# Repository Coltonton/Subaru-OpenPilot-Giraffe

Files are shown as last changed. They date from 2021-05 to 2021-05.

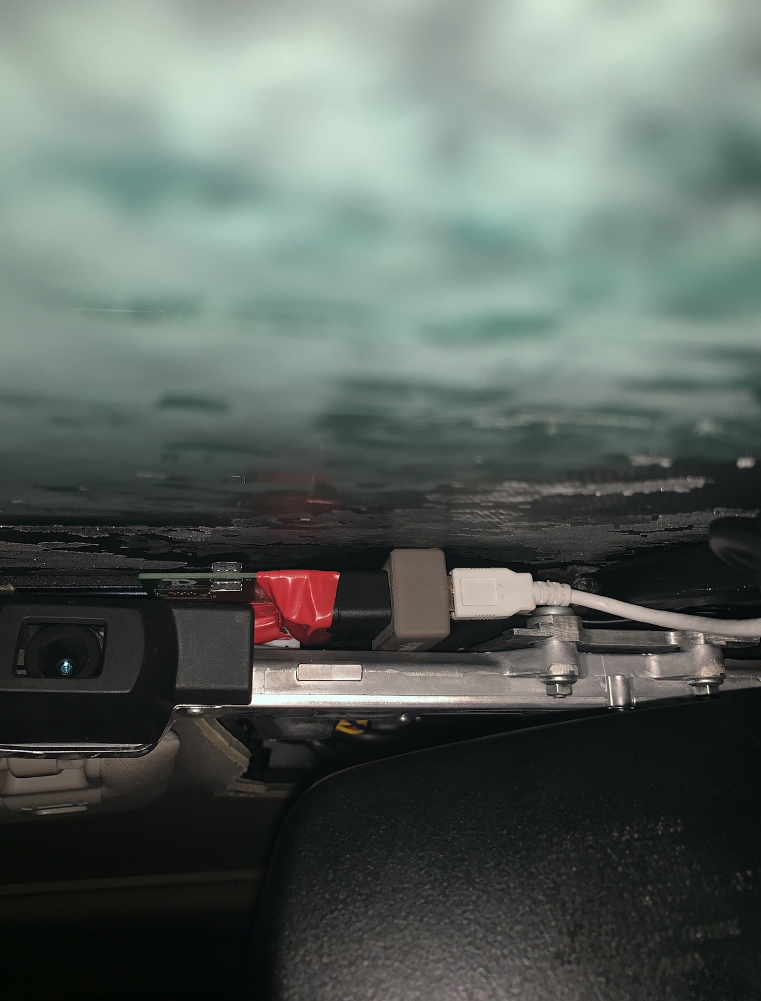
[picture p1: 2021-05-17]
Pictures/V3/Installation Example.jpg

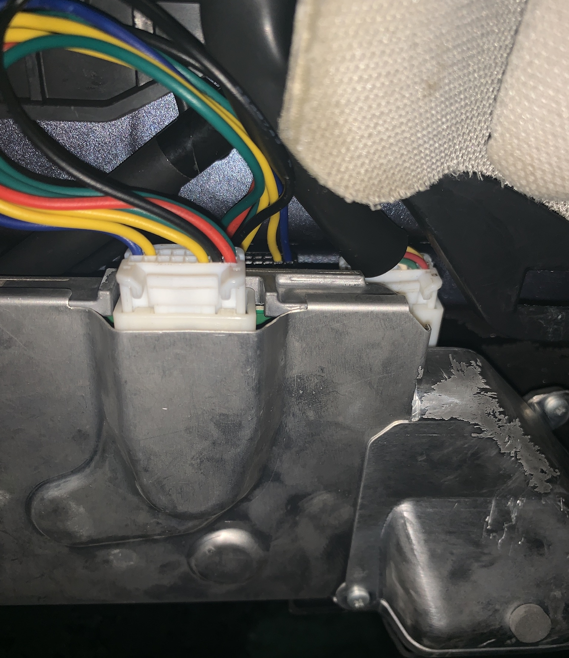
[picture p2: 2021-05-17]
Pictures/V3/3.0-3.6 Installation Example.jpg

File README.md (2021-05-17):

 
# Subaru-OpenPilot-Giraffe(s) 

Here lies the olden and golden days of OpenPilot with Giraffes! You can use this product to interface with the CAN bus on your Subaru vehicle at EyeSight, giving the bonus ability to isolate the EyeSight module on its own separate CAN network for vehicle research, and hacking. 

Some of the Giraffes have mistakes, everything in the `/Legacy Archival Giraffes` folder is just that, a digital archive of most of my work. Most of the "development" Giraffes are lost to time and poor archival management, but live in the release of that version. DO NOT use these files as reference to build your own. ONLY use Austin, Cynthia, or Linda. 

- Intended to be used with a [Comma.ai White or Grey Panda](https://comma.ai/shop/products/panda) 

# Versions  
## -V3- 
 

3.0 Was the real move and evolution, finally fitting it in the cover (Also what the **Smol Bugsy Giraffe** tried to accomplish but in a different way.) I decided to stick on this path for a variety of reasons! I figured out there was no room under the cover... HOWEVER there was tons of room between the top of the EyeSight unit and the roof of the car. I already basically figured it out tho with [V1.1](#). Sometimes you have to look to the past to answer questions today! Again I was over-Zellous with V1.1; but with sure luck, the space allotted to me by the Subaru engineers was a near perfect fit for Panda... Not even a MM of clearance at the smallest point. Working even more perfectly. So is born V3! Only taking to V3 Rev 4 (NIKI) to come up with the perfect and final layout; even solving my switch problem by making the board big enough to where the switches would just be at the gap between the windshield and trim piece. giving a still invisible appearance, but not to difficult to actuate! Progress was made here!  

The V3 also brought reverse compatibility with already dead hardware (The Comma NEO) And was designed to have the factory connector pass above the EyeSight camera unit, plug into giraffe, then having a jumper connector to EyeSight. This ended up only being a possibility for the Legacy/Outback models. All other Subarus did not have the room for the chonky stock connector. Sparking V3.7+ with its Y connector to pass above the camera unit. (I still prefer the Linda design, was nicer and ALOT easier to produce....) 

### -V3.8.3 Austin- 
 

This is a very special edition of the Subaru Giraffe, not only is it the last version to be released; but it was sold as special edition Giraffe. Released in a special blue PCB and dedicated to the memory of my friend and classmate from grade school, Austin, who was tragically taken from us March 20th, 2019; at the too young age of 19. Until we meet again... 

This revision is still very near and dear to my heart and it pained me to no longer use it in my vehicle daily being forced to upgrade to a Black Panda, it's now on my desk where I get to see it daily. But enough with the wishy-washy crap and onto the info! As you can prolly tell by the x.x.3 i screwed this revision up.... a-couple times.... 

- The DeFacto Standard, this is what you should use! 

- Is the "gloabal platform" release Giraffe for use in all Subarus, whereas all previous V3 Giraffes were designed around a 2015 Legacy (and has a lot more room to play) 

- Replaced the 3.7 Cynthia as this version was a 3.7 special edition! But its the same thing 

### -V3.7 Cynthia- 

 
- First iteration of the Subaru global support 

- See [Austin](#V3.8.3-Austin) for details, they are the same, [Austin](#V3.8.3-Austin) is just a special edition of Cynthia with more beautiful routing! 

### -V3.6 Linda- 
 

- 2015-2019 Legacy/Outback Only 
- Added Subaru RAB Support 
- Added New Comma (Camera on CAN 3 instead of 2) Support 

### -V3.4 Niki- 
 

- 2015-2019 Legacy/Outback Only 
- Non RAB (Reverse Automatic Braking) Subarus ONLY 

### -V3.2 & V3.3 Gem- 
 

- 2015-2019 Legacy/Outback Only 
- Non RAB (Reverse Automatic Braking) Subarus ONLY 

### -V3.1 VIKI- 
 

- What Autum was supposed to be 

### -V3.0 Autumn- 
Dedicated to the memory of a co-worker who died unexpectedly, Autumn, to launch the 3rd generation of Subaru Giraffes (Non Working) 

## -V2- 
 

2.0 is a perfect example of my mind thinking more complex at first then working to simplicity. The idea with this weird Giraffe was to be like all the other Giraffes at the time where the board plugs directly into the cameras and the factory harness plugs into the board. This was a stupid idea as it would require cutting the EyeSight cover (or having it off) Witch we already had agreed was not going to happen... Too ugly, and expensive. It made a great development board as we were still trying to get the Subaru port "functional" It even uses the exact dip switches as the others. But with a twist... My overengineering mind went crazy with ideas as I knew the Giraffe would end up getting hidden up in the cover; I still wanted an easy way to have the traditional "switches" to be able to toggle Stock/Openpilot. What did I do? the only logical thing of course relays that could be hooked up to a switch and ran! It was a development platform so the *idea* was to be able to choose between dip switches or relay. I'm pretty sure they wouldn't work anyway as they are Solid state relays... idk... never tried them... 

It's funny because a year later Comma.ai made the **Subaru Access Point** with... a relay..... to control switching.... Eventually becoming the [Comma Harnes](https://comma.ai/shop/products/comma-car-harness)....  Admittedly they did do it better.... Except for using the USB Type-C Connectors...... It would of been the eventual evolution of my product to go back to relay control anyway! I take one big leap, have to crawl backwards crying and work my way back.....   

## -V1- 
 

Mr Overthinkers, first Giraffe overthink, before I found out Panda did fit somewhere in the EyeSight cover I had the brilliant idea to tear apart the Comma Panda and just put it on the Giraffe 

Rip White Panda - unknown year 

Features Eletronic relays that could be used to solve our switch situation (im writing this in reverse order so see V2 for info on that....) 

## -V0.1- 
 

**My First PCB** features include: 
- 90deg track corners 
- Weird angle lines (non 45deg multiple) 
- OBD socket doesn't even fit 
- Eyesight connectors don't even fit 
- No idea what I was doing (clearly) 
- Absolute trash 
- Prolly will blow up your car

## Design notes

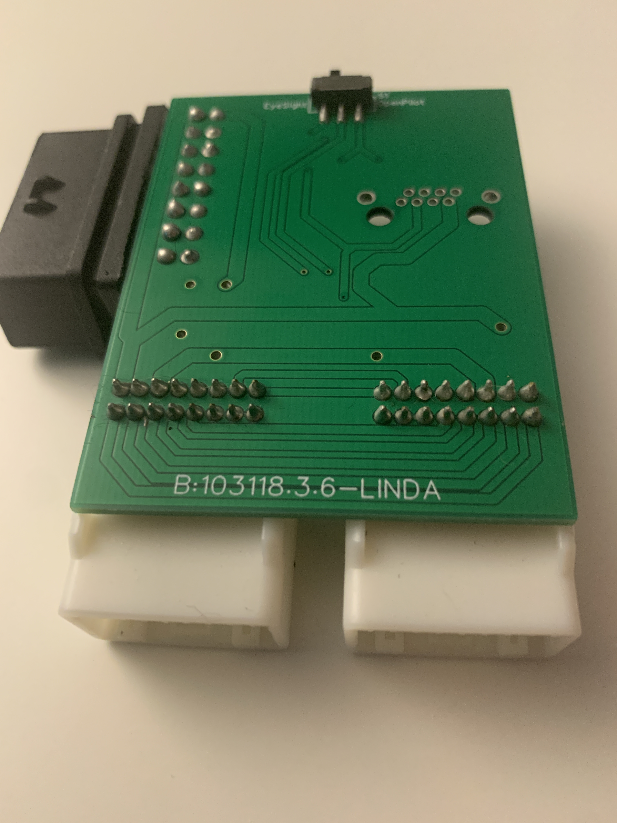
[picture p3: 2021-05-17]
Pictures/V3/3.6-Linda(1).JPG

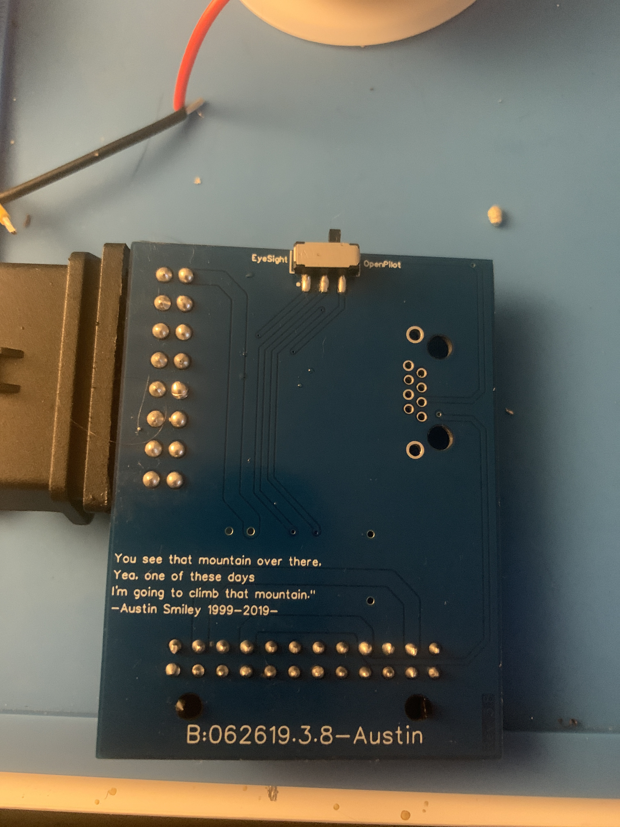
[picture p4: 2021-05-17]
Pictures/V3/3.8-Austin(1).JPG

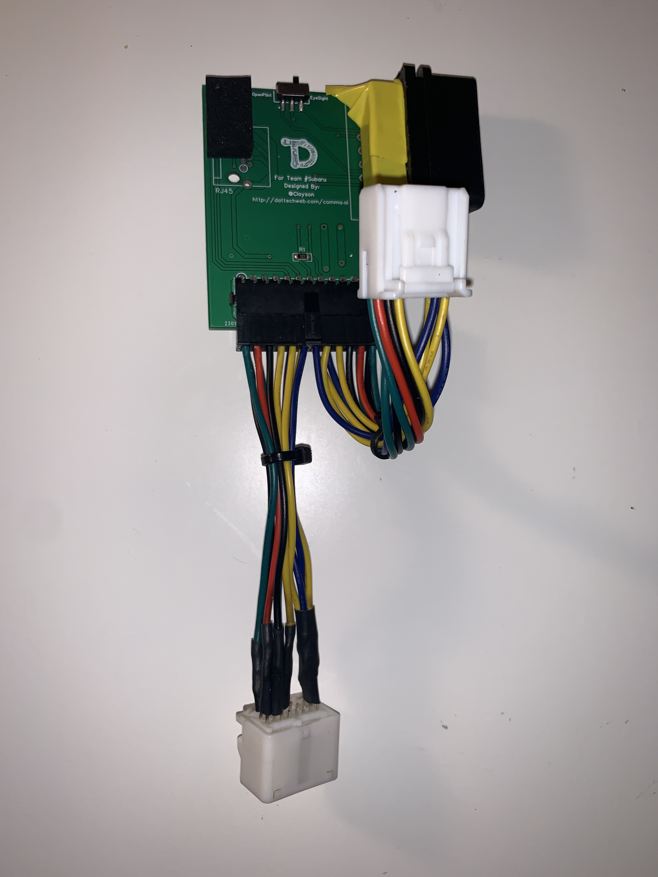
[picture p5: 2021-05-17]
Pictures/V3/3.7-Cynthia(5).JPG

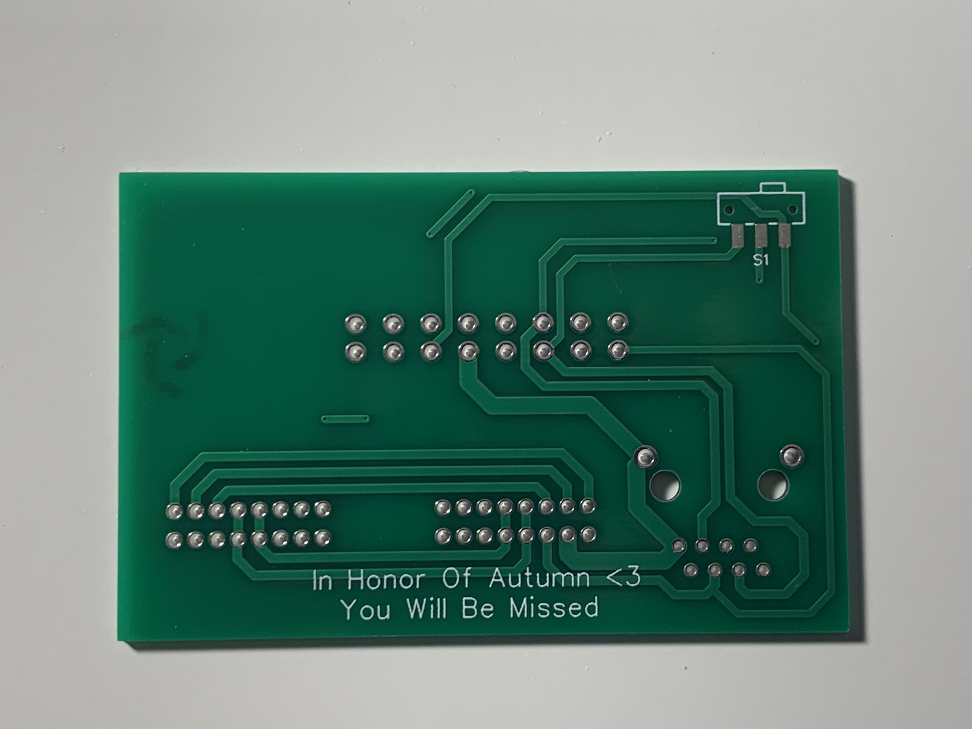
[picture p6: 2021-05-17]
Pictures/V3/3.0-Autumn.JPG

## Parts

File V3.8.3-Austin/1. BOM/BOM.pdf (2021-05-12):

Manufacturer Part Number | Manufacturer | Digi-Key Part Number | Customer Reference | Reference Designator Quantity
2-794617-4 | TE Connectivity AMP Connectors | A30304-ND | | Y3 | 1
5-794618-4 | TE Connectivity AMP Connectors | A33262-ND | | CON HEADER F | 1
794610-1 | TE Connectivity AMP Connectors | A30305-ND | | | 24
KTR18EZPJ121 | Rohm Semiconductor | RHM120PCT-ND | | R1 | 1
JS102011SAQN | C&K | 401-1999-1-ND | | CANH & CANL | 2
1318382-2 | TE Connectivity AMP Connectors | A126093-ND | EyeSight Input | Y1 | 1
1318386-1 | TE Connectivity AMP Connectors | A106550-ND | To EyeSight | Y2 | 1
1123343-1 | TE Connectivity AMP Connectors | A107011CT-ND | | | 12
OBDII 16 Pin J1962 F 90deg | Alibaba (Or Me, I Have some) | | | panda | 1
https://www.alibaba.com/product-detail/OBD2-OBDII-16-Pin-J1962-Female_60735154017.html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

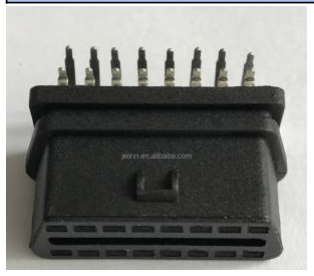
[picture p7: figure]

I Extras of this OBDII Connector
and other parts, And PCBs, feel free to contact me @Coltonton#2169 - Discord

@ sheaf_b - Twitter

https://discord.com/invite/2rxE2r3ywe

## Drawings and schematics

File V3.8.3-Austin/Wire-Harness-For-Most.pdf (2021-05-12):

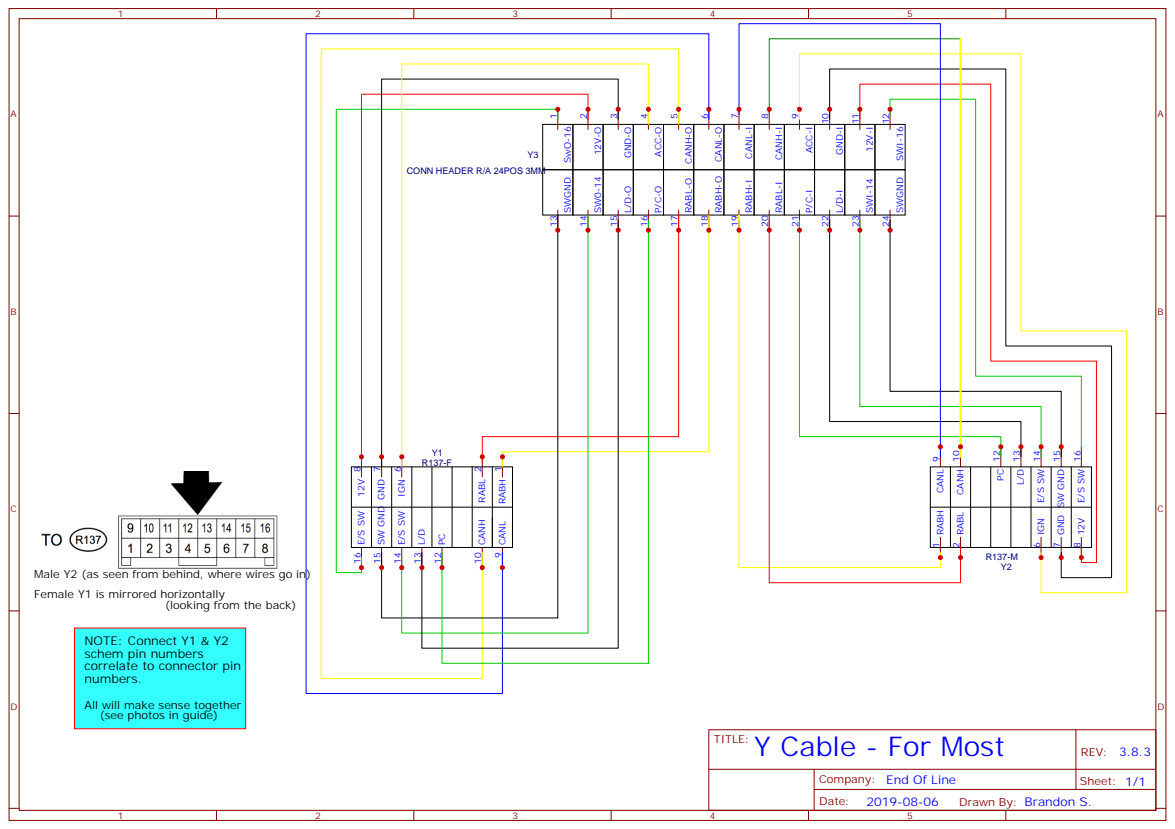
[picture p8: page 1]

Male Y2 (as seen from behind, where wires go in)
Female Y1 is mirrored horizontally

(looking from the back)

NOTE: Connect Y1 & Y2
schem pin numbers
correlate to connector pin
numbers.

All will make sense together
(see photos in guide)

Company: End Of Line

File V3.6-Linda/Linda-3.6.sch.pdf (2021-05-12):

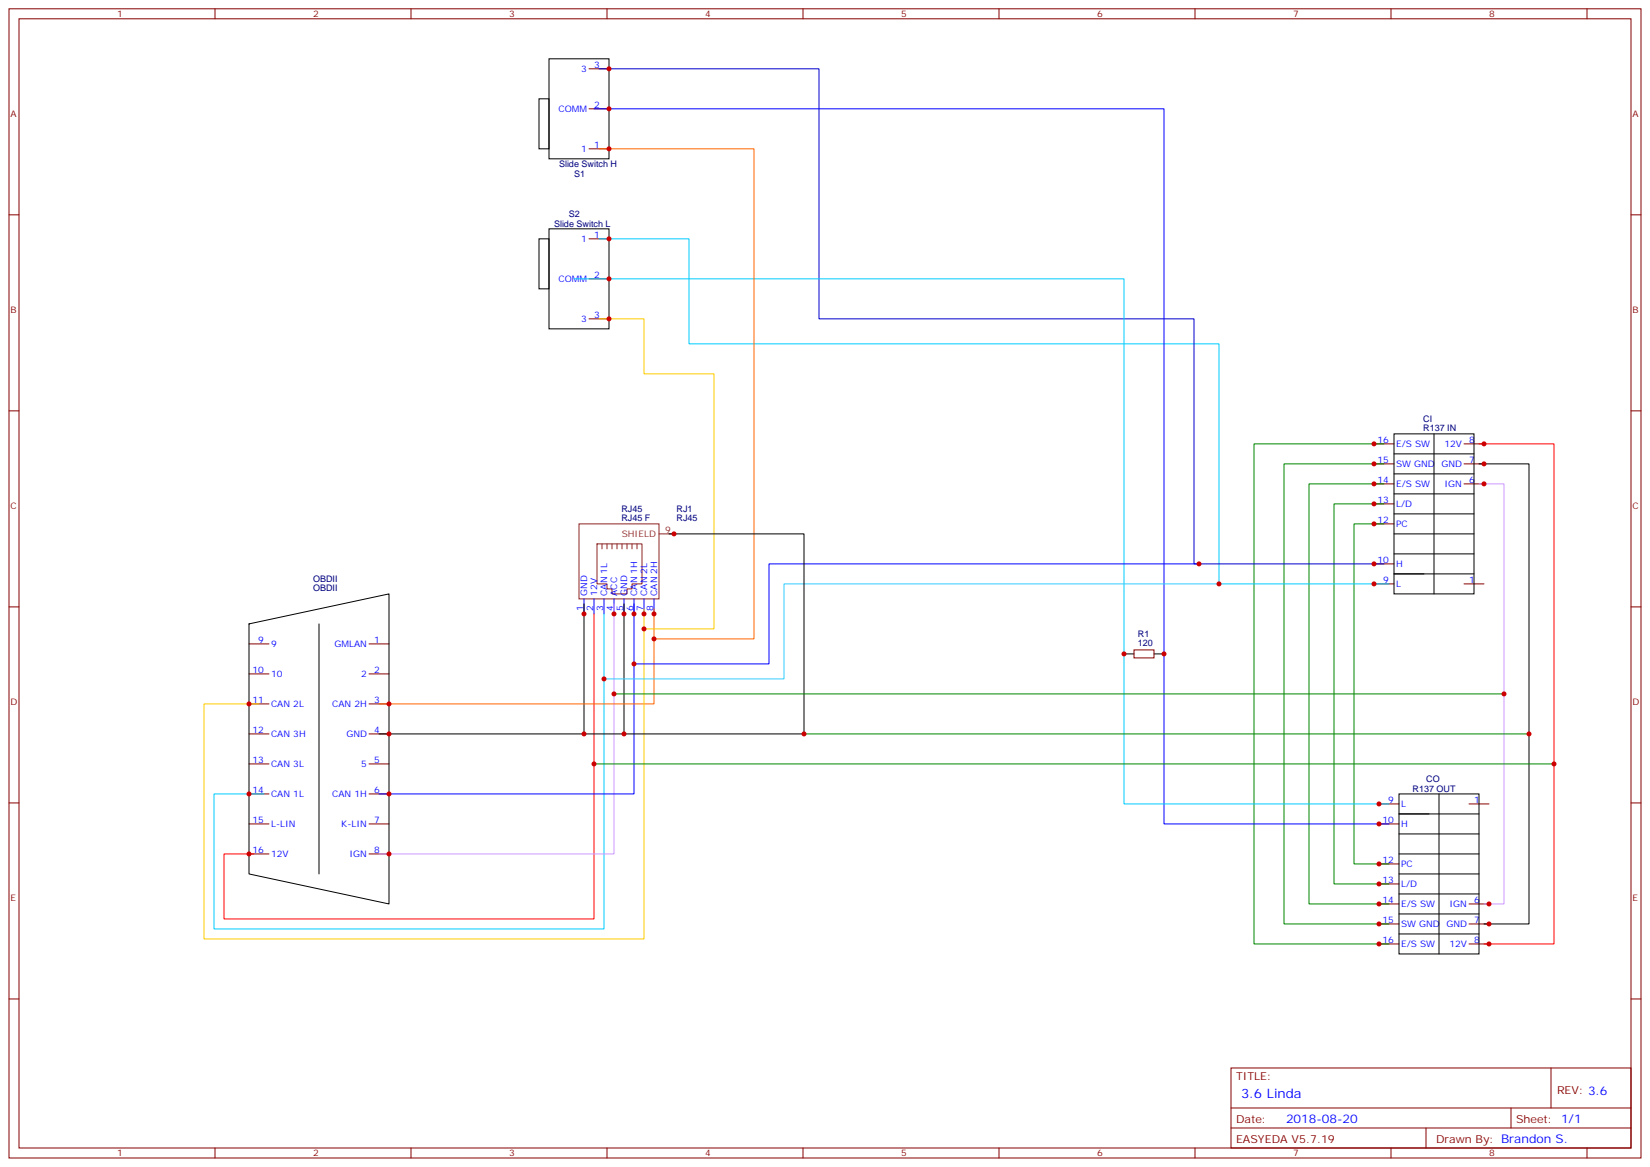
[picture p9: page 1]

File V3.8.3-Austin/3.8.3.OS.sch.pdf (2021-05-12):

# CANH COMM

# CANL COMM

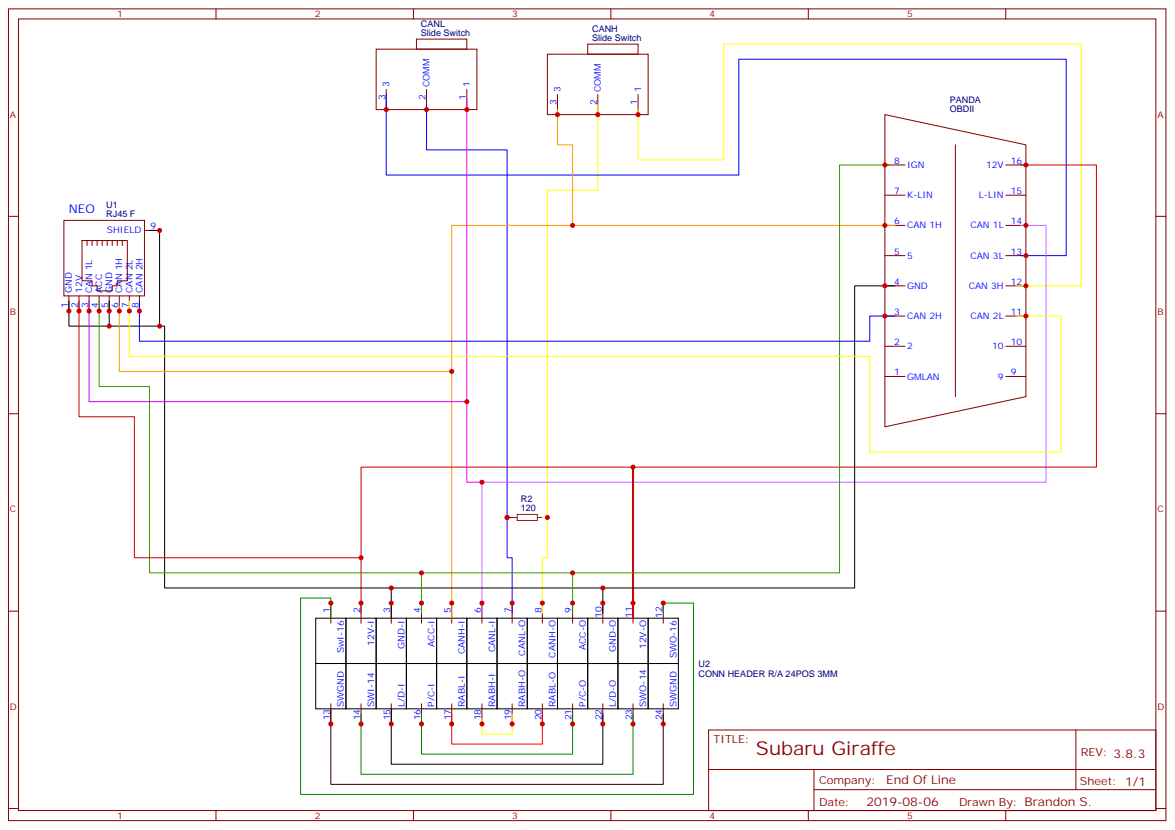
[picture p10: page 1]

Company: End Of Line

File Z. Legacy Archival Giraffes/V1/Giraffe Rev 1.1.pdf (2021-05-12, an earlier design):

A | A

1

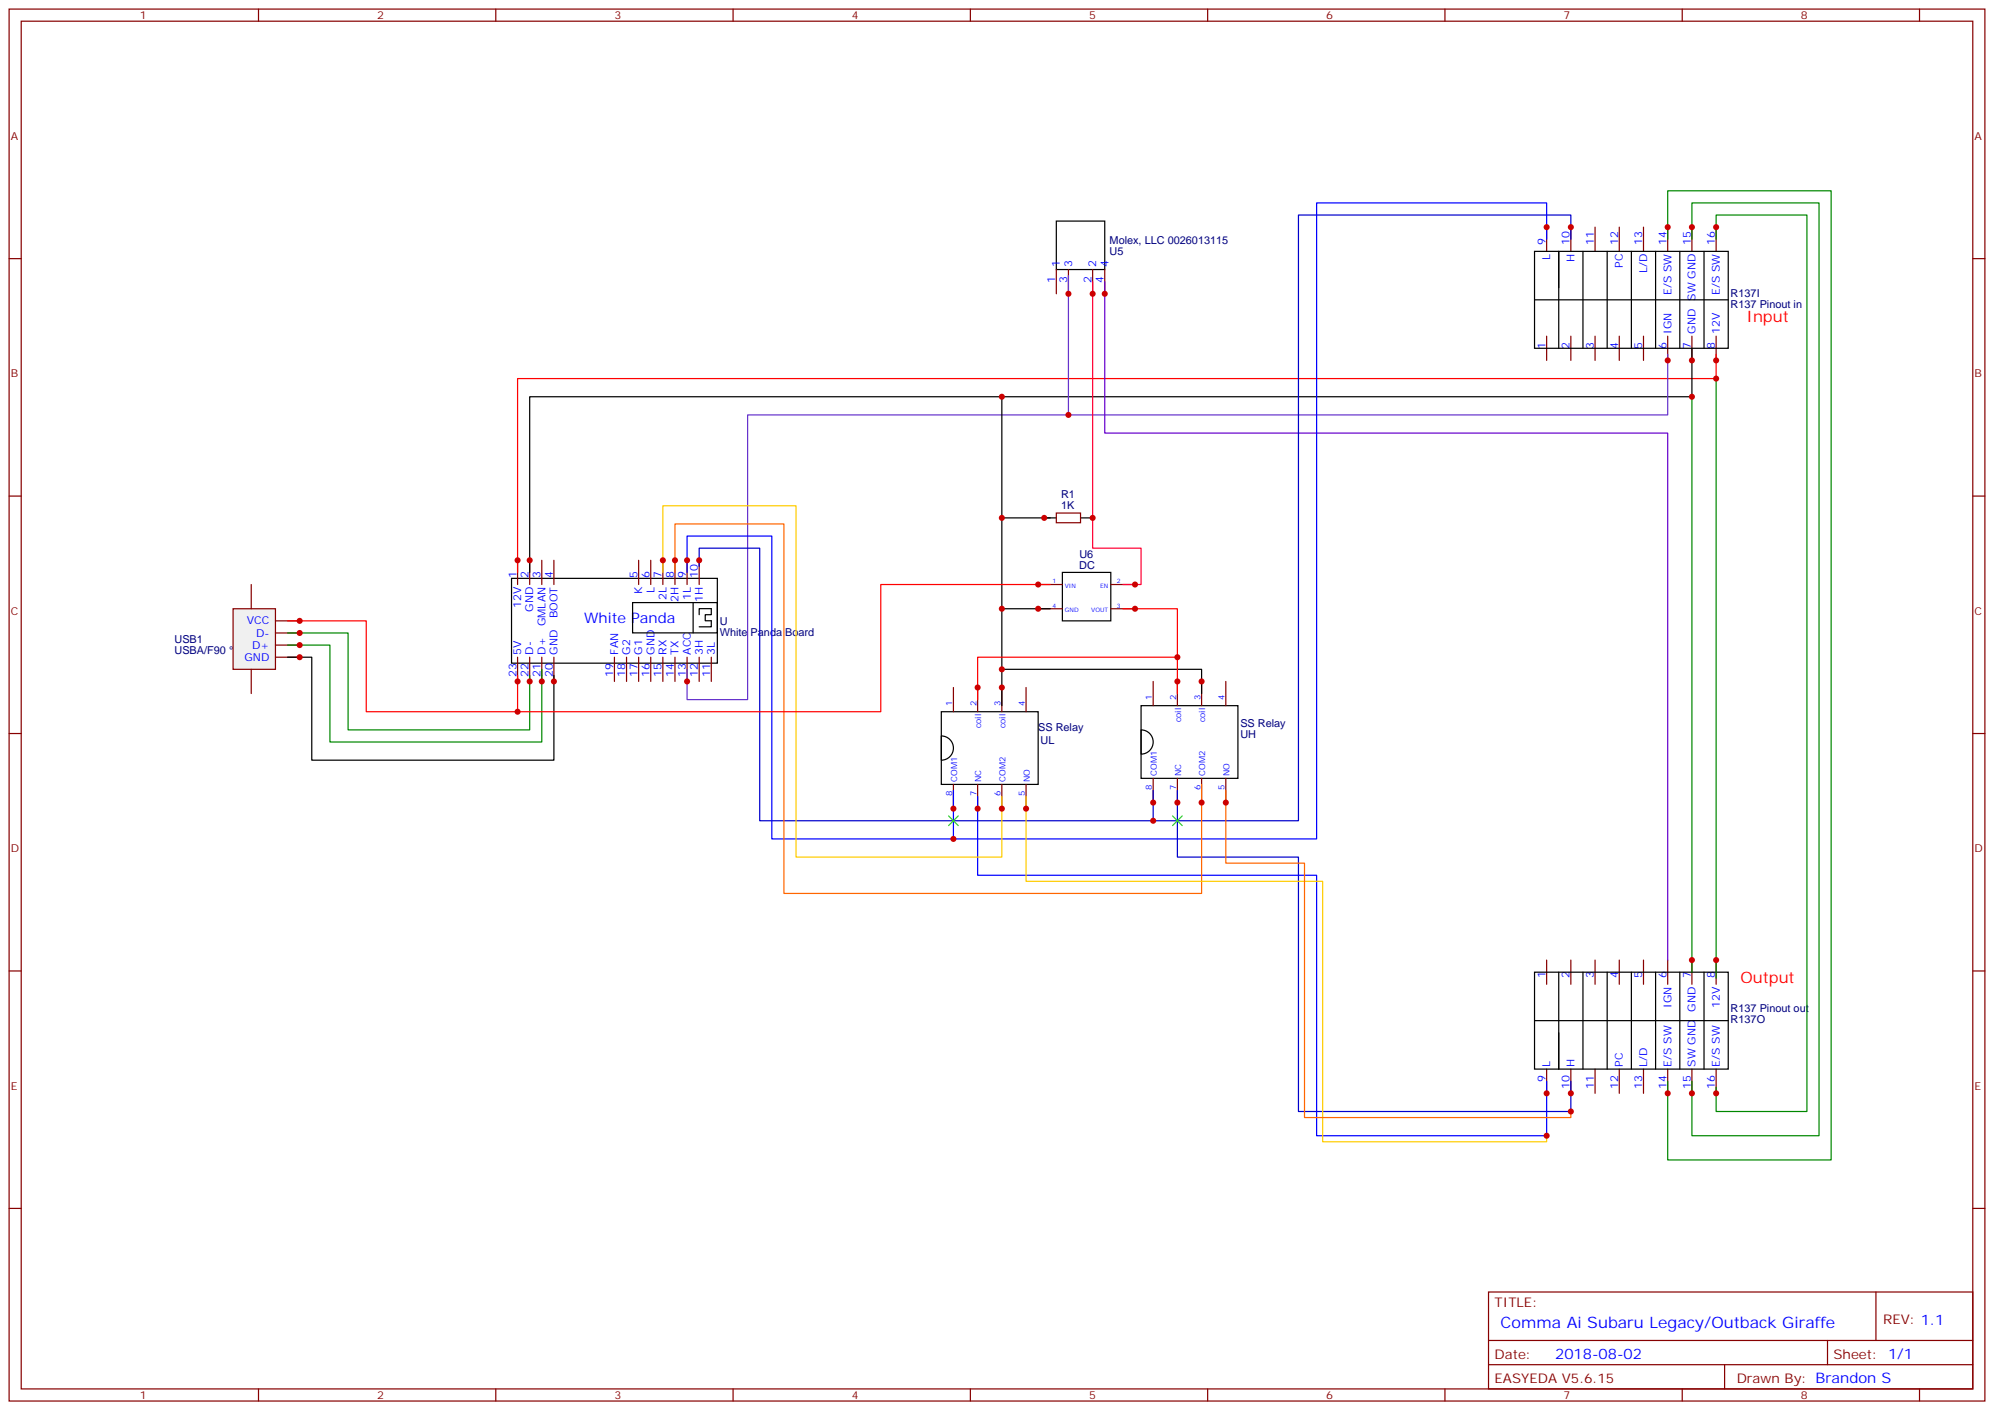
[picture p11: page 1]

3L 11 3H 12 ACC 13 TX 14 RX 15 GND 16 G1 17 G2 18 FAN 19

TITLE:
Comma Ai Subaru Legacy/Outback Giraffe

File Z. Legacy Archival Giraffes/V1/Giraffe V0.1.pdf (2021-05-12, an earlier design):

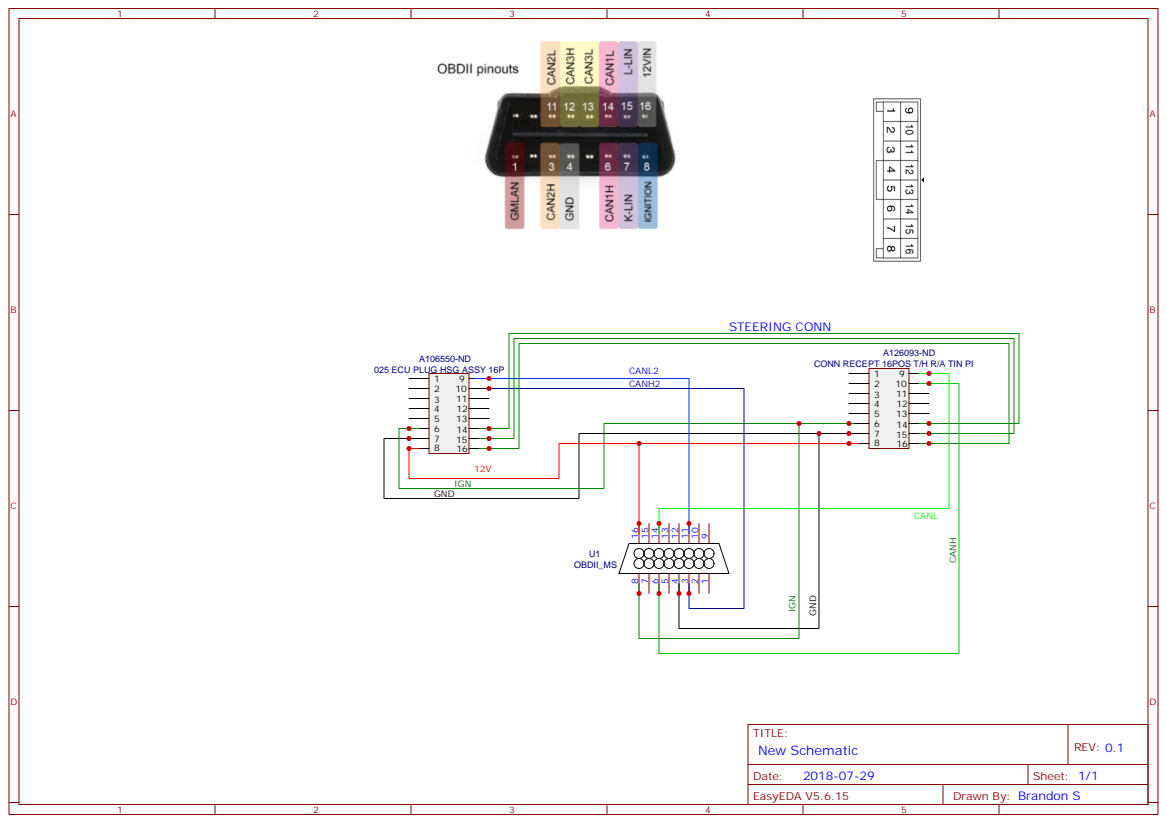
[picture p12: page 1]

CONN RECEPT 16POS T/H R/A TIN PI

025 ECU PLUG HSG ASSY 16P

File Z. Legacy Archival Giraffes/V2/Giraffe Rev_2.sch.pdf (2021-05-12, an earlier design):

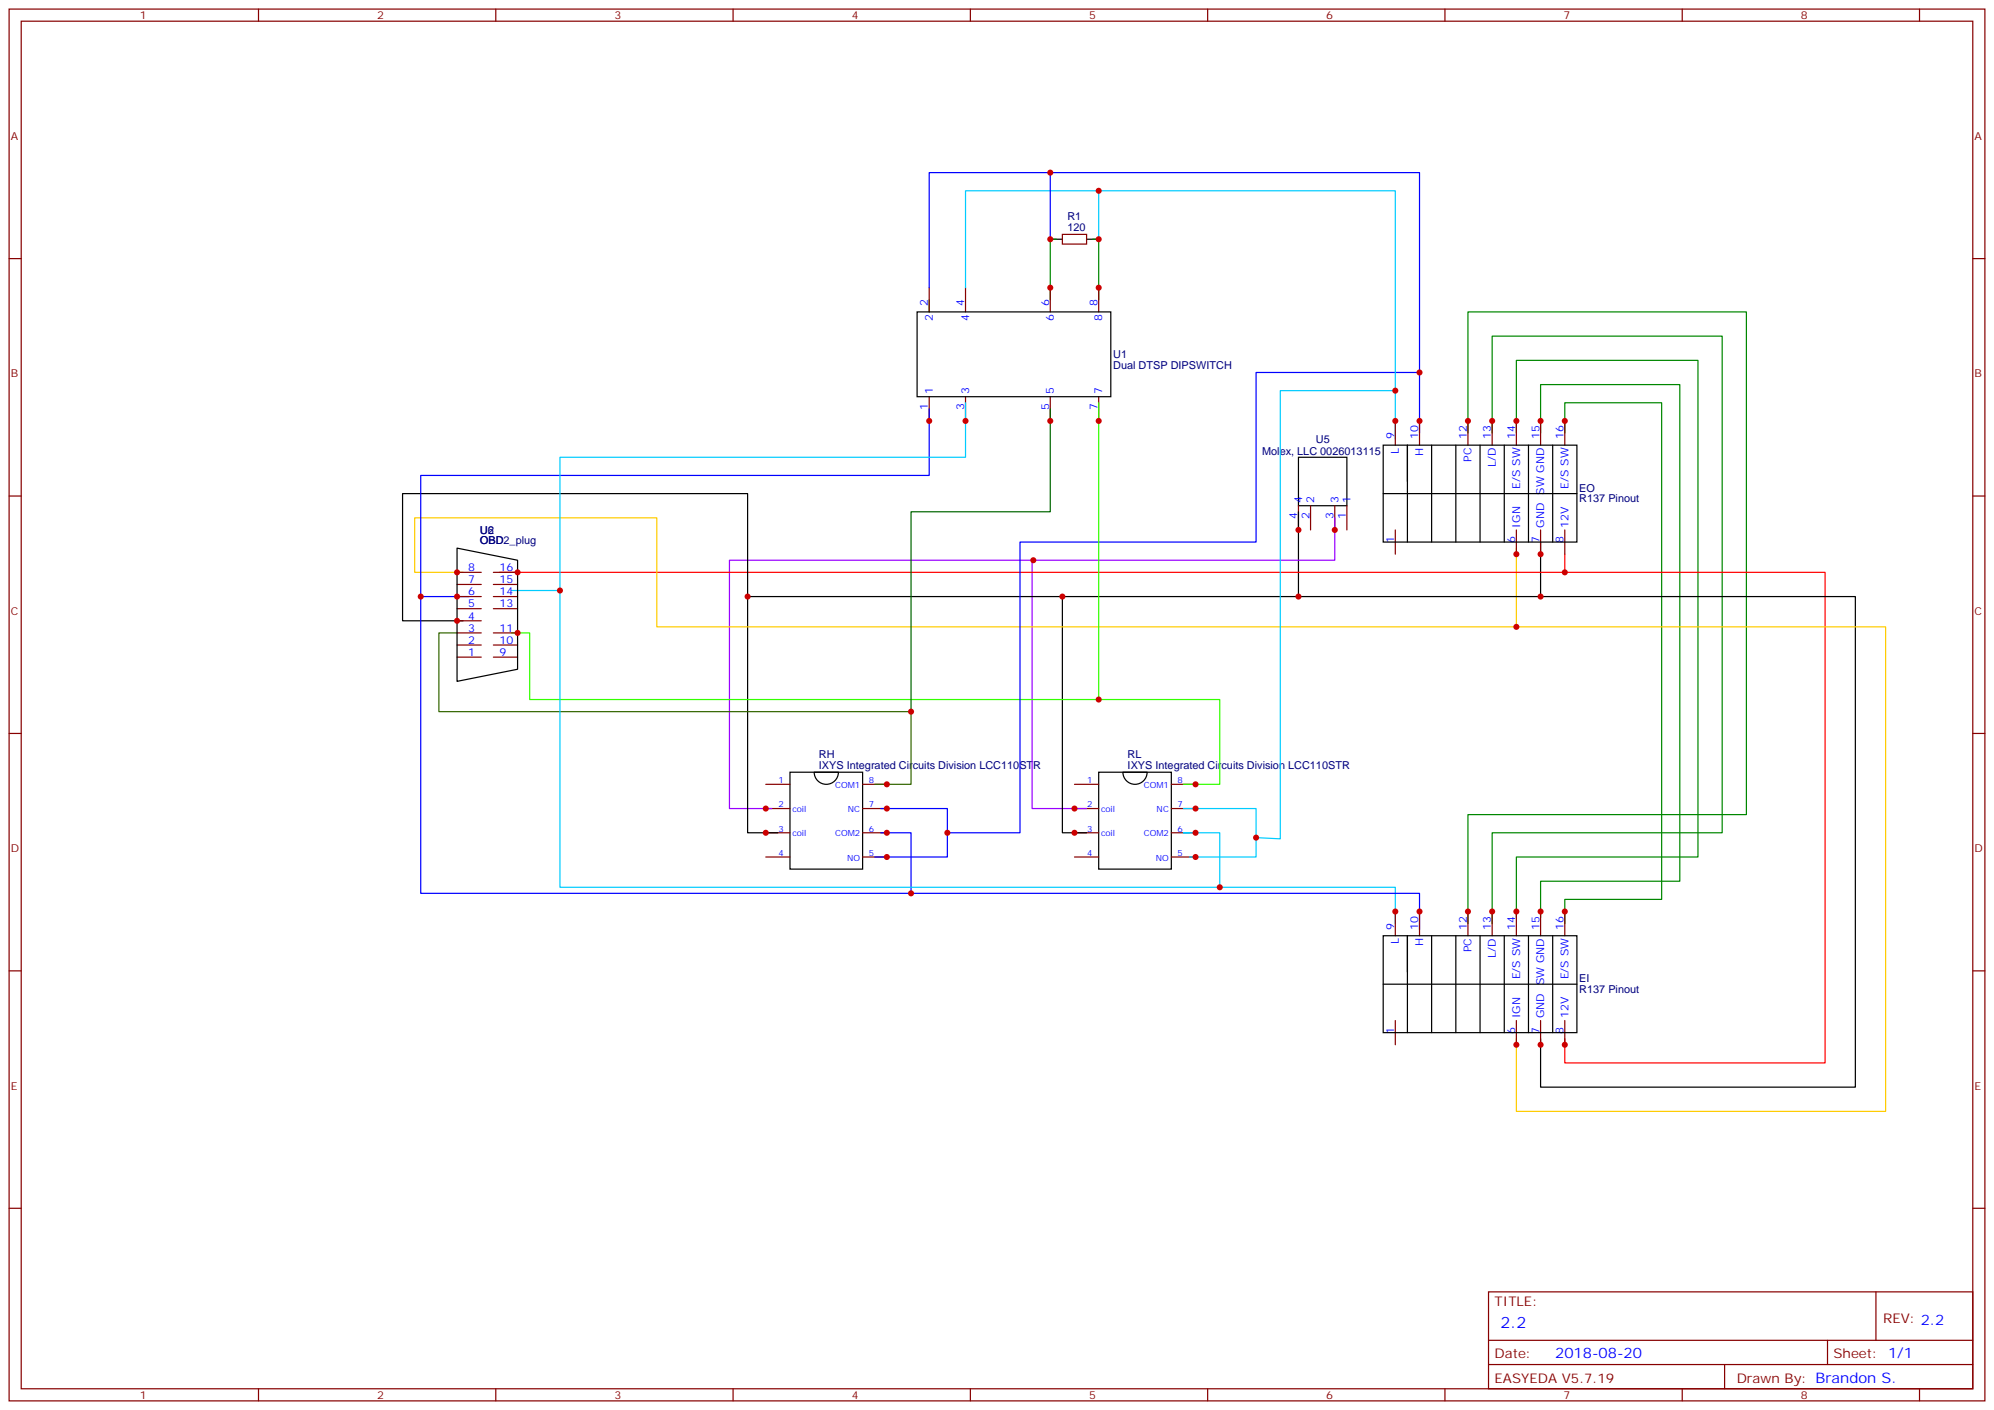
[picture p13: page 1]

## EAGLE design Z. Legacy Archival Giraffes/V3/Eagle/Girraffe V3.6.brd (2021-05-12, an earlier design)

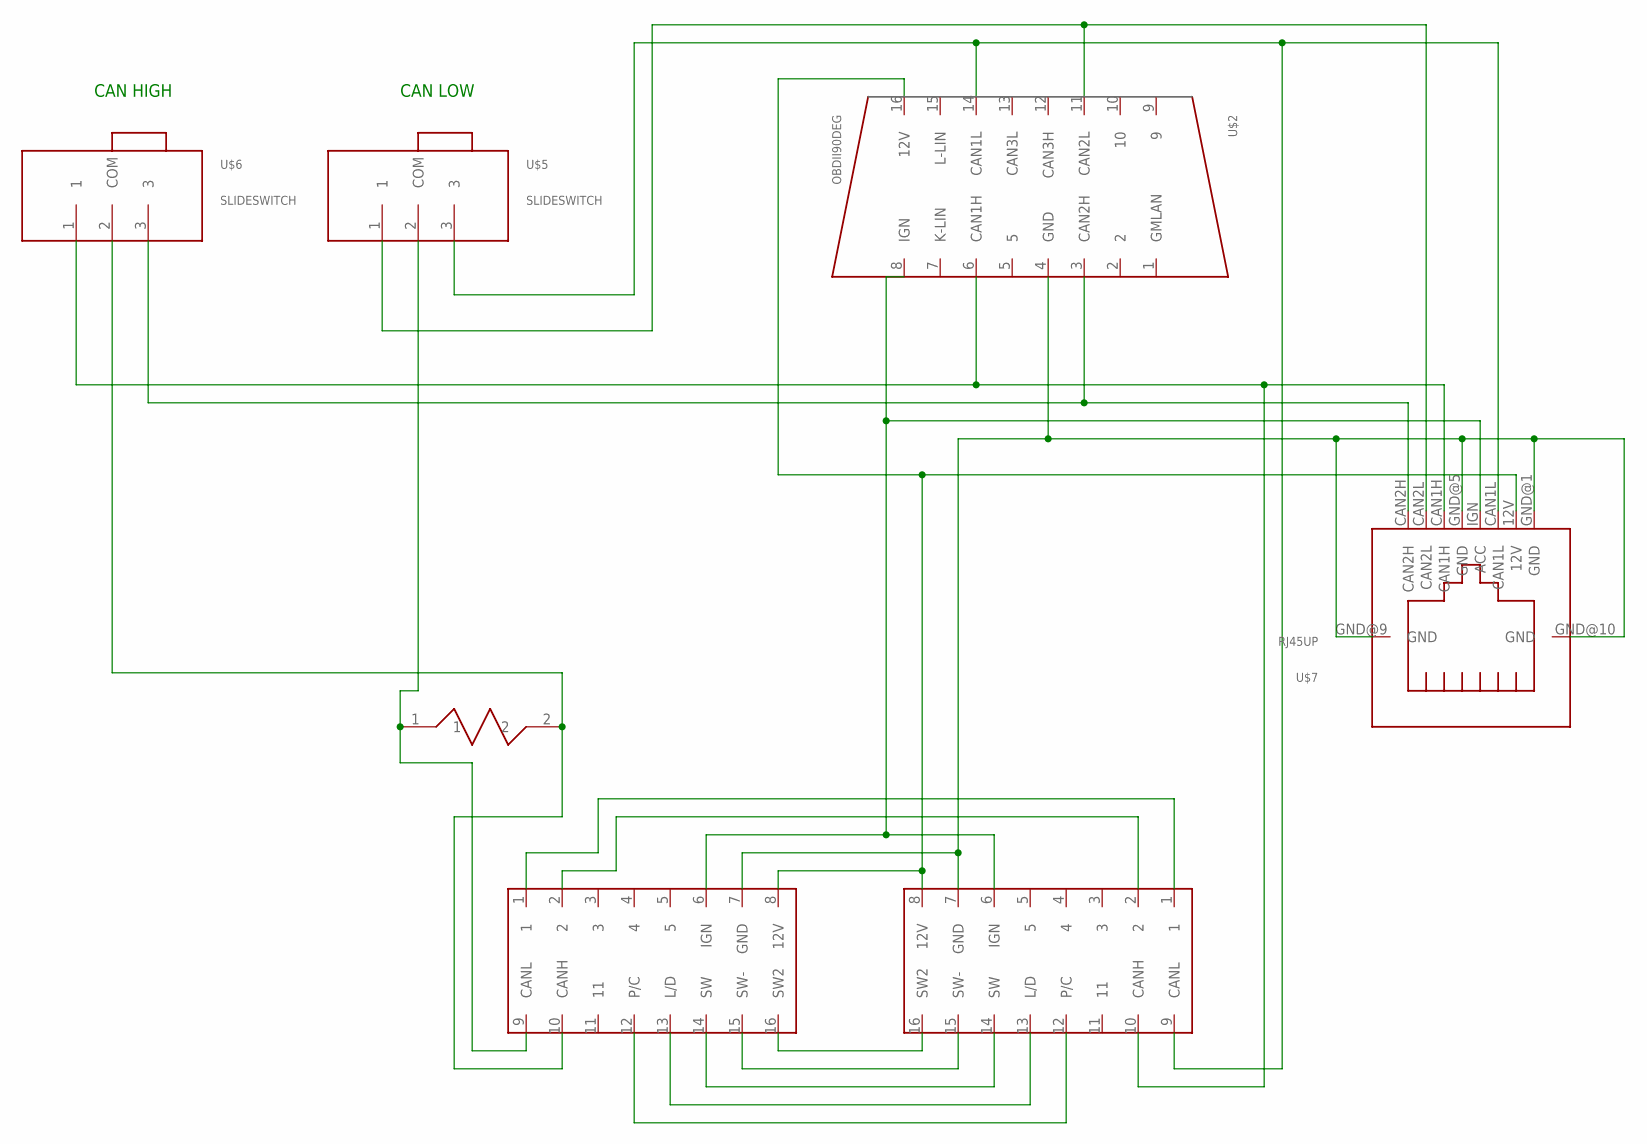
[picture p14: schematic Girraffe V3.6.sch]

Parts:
U$1: 120OHM
U$2: OBDII90DEG; OBDII
U$3: R137IN; R137
U$4: R137OUT
U$5, U$6: SLIDESWITCH
U$7: RJ45UP; VERRJ45

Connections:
12V: U$2.16 (12V), U$3.8 (12V), U$4.8 (12V), U$7.12V
ACC: U$2.8 (IGN), U$3.6 (IGN), U$4.6 (IGN), U$7.IGN (ACC)
GND: U$2.4 (GND), U$3.7 (GND), U$4.7 (GND), U$7.GND@1 (GND), U$7.GND@5 (GND), U$7.GND@9 (GND), U$7.GND@10 (GND)
unnamed: U$1.1, U$4.9 (CANL), U$5.2 (COM)
unnamed: U$1.2, U$4.10 (CANH), U$6.2 (COM)
unnamed: U$2.14 (CAN1L), U$3.9 (CANL), U$5.3, U$7.CAN1L
unnamed: U$2.11 (CAN2L), U$5.1, U$7.CAN2L
unnamed: U$2.6 (CAN1H), U$3.10 (CANH), U$6.1, U$7.CAN1H
unnamed: U$2.3 (CAN2H), U$6.3, U$7.CAN2H
unnamed: U$3.16 (SW2), U$4.16 (SW2)
unnamed: U$3.15 (SW-), U$4.15 (SW-)
unnamed: U$3.14 (SW), U$4.14 (SW)
unnamed: U$3.13 (L/D), U$4.13 (L/D)
unnamed: U$3.12 (P/C), U$4.12 (P/C)
unnamed: U$3.2, U$4.2
unnamed: U$3.1, U$4.1

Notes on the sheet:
CAN LOW
CAN HIGH

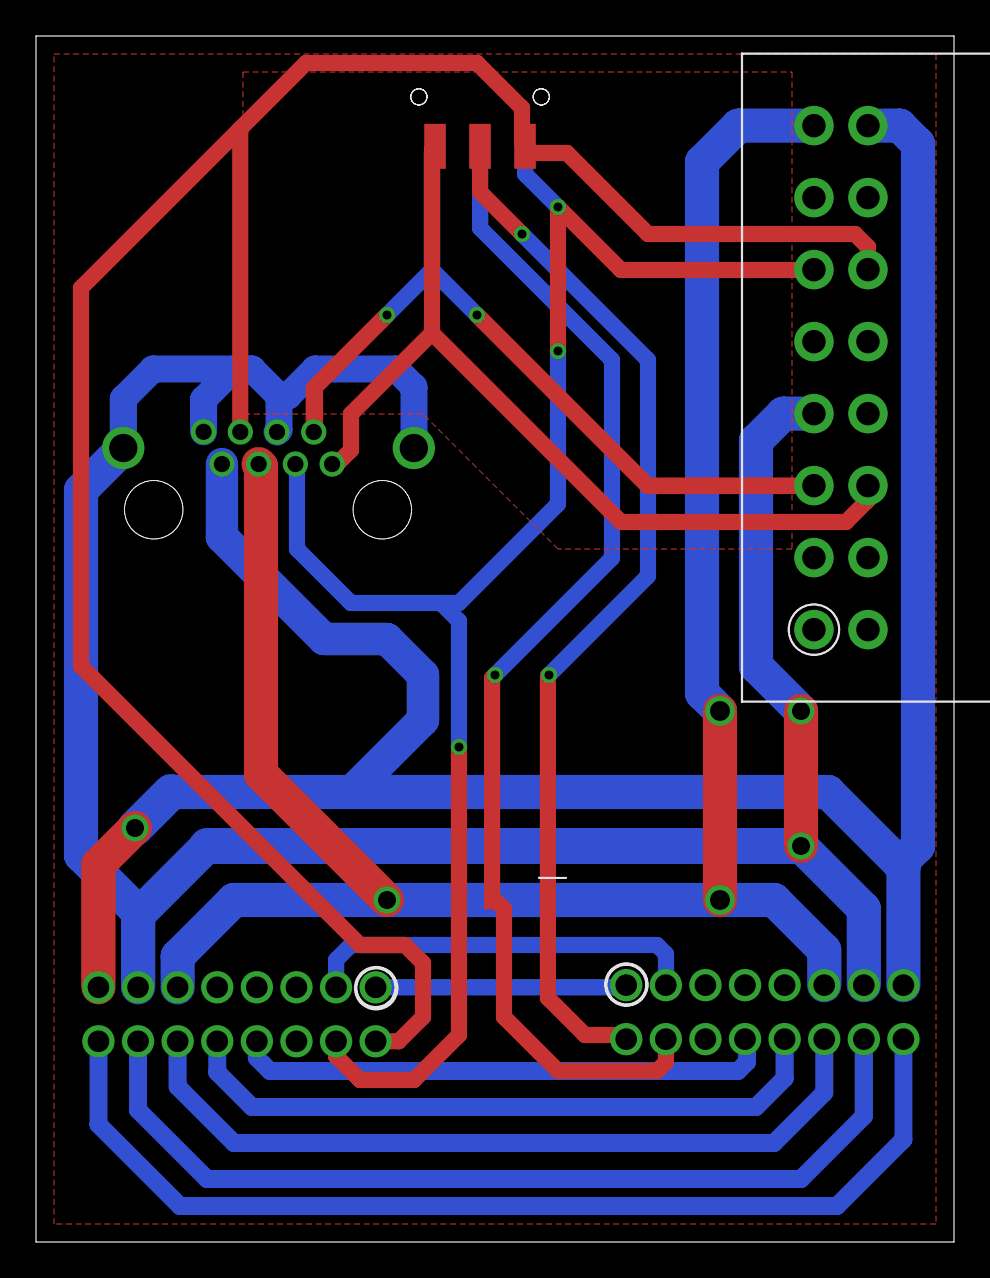
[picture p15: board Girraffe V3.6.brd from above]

Board: 2 copper layers, 51.0 x 67.0 mm, 7 parts (1 on the bottom side), 16 nets.

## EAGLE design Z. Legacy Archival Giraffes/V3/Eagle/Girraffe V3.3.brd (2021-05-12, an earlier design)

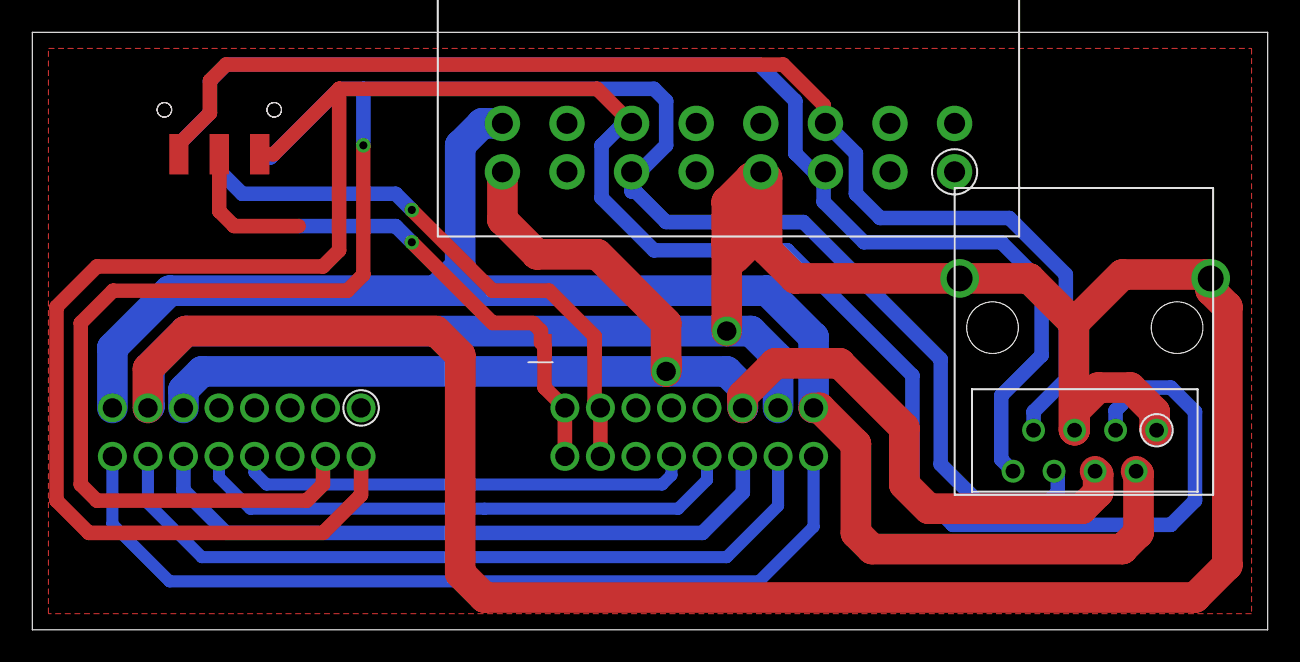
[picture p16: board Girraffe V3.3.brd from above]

Board: 2 copper layers, 76.5 x 37.0 mm, 7 parts (1 on the bottom side), 14 nets.

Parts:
U$1: 120OHM
U$2: OBDII90DEG; OBDII
U$3: R137IN; R137
U$4: R137OUT
U$5, U$6: SLIDESWITCH
U$8: RJ45

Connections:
12V: U$2.16, U$3.8, U$4.8, U$8.12V
ACC: U$2.8, U$3.6, U$4.6, U$8.IGN
GND: U$2.4, U$3.7, U$4.7, U$8.GND@1, U$8.GND@5, U$8.GND@9, U$8.GND@10
unnamed: U$1.1, U$4.1, U$4.9, U$5.2
unnamed: U$1.2, U$4.2, U$4.10, U$6.2
unnamed: U$2.14, U$3.9, U$5.3, U$8.CAN1L
unnamed: U$2.11, U$5.1, U$8.CAN2L
unnamed: U$2.6, U$3.10, U$6.1, U$8.CAN1H
unnamed: U$2.3, U$6.3, U$8.CAN2H
unnamed: U$3.16, U$4.16
unnamed: U$3.15, U$4.15
unnamed: U$3.14, U$4.14
unnamed: U$3.13, U$4.13
unnamed: U$3.12, U$4.12

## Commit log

2021-05-12 Initial Upload of Files
    [Bom.xlsx, Buggsy Girrafe.brd, Buggsy Girrafe.sch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]
2021-05-14 Updates for Readme and File Struct
    [Bom.xlsx]
